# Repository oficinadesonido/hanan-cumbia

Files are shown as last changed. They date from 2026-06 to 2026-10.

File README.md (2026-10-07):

# HANAN CUMBIA · Batería electrónica (Arduino Nano)

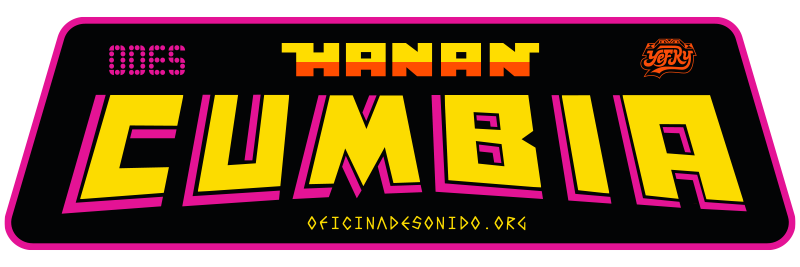
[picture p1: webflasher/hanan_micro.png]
HANAN CUMBIA


Caja de ritmos / batería electrónica tropical de **Oficina de Sonido** (desde 2020). Plataforma
**Arduino Nano (ATmega328P)** + DAC externo **MCP4901** por SPI, síntesis por wavetable.
Dos versiones de hardware con **el mismo circuito y el mismo firmware**:

| Versión | PCB | Qué es |
|---|---|---|
| **Clásica** | `hardware/hananClasicaPcb/` | 77×92 mm, 8 pulsadores en placa, jack DC 9 V, va en caja. |
| **Mini** | `hardware/hananMiniPcb/` | 150×75 mm (= panel), calado para 4 botones arcade, se alimenta por USB. Para talleres. |

El rediseño 2026 en ESP32 es otro producto: `../hanan-mk2/`.

## 🔥 Web Flasher / Hanan Estudio

👉 **https://oficinadesonido.github.io/hanan-cumbia/webflasher/** (GitHub Pages desde `main`;
todo push a `main` queda publicado al toque). Chrome/Edge/Opera de escritorio (Web Serial).
`hananFabrica/` es el flasher de fábrica (solo firmware). Notas de diseño en `webflasher/README.md`.

## Estructura

```
hardware/hananClasicaPcb/   PCB clásica v2.0 (KiCad 10)      ← ver su README
hardware/hananMiniPcb/      PCB Mini v2.0 (KiCad 10)
firmware/hanan26Taller/     Firmware actual (Taller 2026; de acá salen los builds del Estudio)
firmware/tests/             Sketches de diagnóstico (DAC, potes, pines, motor de audio)
firmware/legacy/HTRCMB_10/  Firmware original del que deriva todo (histórico)
webflasher/                 Hanan Estudio + Lab + flasher (HTML/JS, STK500v1)
hananFabrica/               Flasher de fábrica
docs/                       Revisión eléctrica, capas EasyEDA, SVG de calados del panel Mini
```

Perfil de fabricación: **tht** (JLC solo PCB, se suelda en taller). Regla: toda placa lleva en silk
`<proyecto> vX.Y AAAA-MM-DD` = nombre del zip de gerbers (title block del PCB).

## Cambios v2.0 de ambas PCB (2026-10-07)
- RC en Vref del DAC (R6 1k + C2 10 µF) y 100 nF en Vdd (C3): el ruido del USB/cargador ya no entra
  directo a la referencia del audio. Pads del LED RGB agrandados. Rótulo de versión en silk.
- Mini: los 8 pads de los cables de los botones arcade pasan a una columna de pads grandes en pares
  (blanco/rosa/amarillo/verde + GND), zona GND en toda la placa.
- Detalle y pendientes en `docs/revision-electronica-mini.md` y `hardware/hananClasicaPcb/README.md`.

## Firmware: cambios respecto al original
- **Fix de tempo (pitch ⇒ BPM):** el secuenciador se clockeaba con `micros()`, que bajo la carga de la
  ISR de audio perdía tiempo. Ahora el tempo se cuenta con un reloj estable dentro de la ISR (`audioclock`).
- **BPM por defecto = 90**; **potenciómetros invertidos** (A0/A1); **A14 neutralizado** (solo 2 potes);
  **piso de pitch en A1** para que el sample siempre suene completo.

```bash
arduino-cli compile --fqbn arduino:avr:nano firmware/hanan26Taller
arduino-cli upload  --fqbn arduino:avr:nano -p /dev/ttyUSB0 firmware/hanan26Taller
```
Requiere el core `arduino:avr` y las librerías `Bounce` y `DAC_MCP49xx`.

## Historial
El material viejo (Placa_2021, HTR_2023, hanan25, audios, códigos, backups) se movió el 2026-10-07 a
`3-archivo/hanan-cumbia-historico/` (y está en el respaldo TOSHIBA). Repo viejo `oficinadesonido/HananCumbia` (2023).

---
🤖 Mantenido con ayuda de [Claude Code](https://claude.com/claude-code) · oficinadesonido.org

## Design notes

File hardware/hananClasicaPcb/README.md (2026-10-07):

# hananClasicaPcb — Hanan Cumbia clásica, PCB principal v2.0 (2026-10-07)

Proyecto KiCad 10 armado el 2026-10-07 a partir de:
- **PCB:** `../hanan25.kicad_pcb` (77.1×92.1 mm; mismo diseño que `Hanan.kicad_pcb`/`Hanantaller.kicad_pcb`/`HTR_2023`;
  última fabricación JLC Y194, 10 u., 2025-11-14).
- **Esquemático:** copia de `hanan26/hananMiniPcb/hananMiniPcb.kicad_sch` (mismos refs y UUIDs que la PCB) +
  `J1` jack DC y `D2` diodo serie a `+9V`/VIN (net `VIN_JACK`). El `.sch` legacy `BD1.sch` queda como histórico.
  Los enlaces sch↔pcb coinciden (UUID de símbolo = path de huella), así que "Actualizar PCB desde esquemático" en el GUI
  no debería mover nada.

## Cambios v2.0 (iguales a hananMiniPcb v2.0)
- `R6` 1 kΩ + `C2` 10 µF: RC en Vref del MCP4901 (U1.6, net `VREF`); `C3` 100 nF en Vdd (U1.1). Cara B, borde izquierdo
  junto a R3 (R6 x=52.6, C2 x=51.8, C3 y=105.8). El +5C que entraba al pad 6 se cortó en (61.9,112.6) y se reruteó.
- Pads de `D1` (LED RGB) 1.25×1.8 mm (anillo 0.175 ≥ 0.13 JLC). Solo en la instancia del PCB.
- Title block (rev `v2.0`, fecha) + silk `hananClasicaPcb ${REVISION} ${ISSUE_DATE}` en F y B (y=160.6).
- DRC: 0 sin conectar, 0 errores. Warnings preexistentes: libs `OdeS`/`SWITCH`/`Arduino` no configuradas, silk al
  borde, textos XA1, vía colgada de `Net-(J2-Pad1)` en (113.3,149.7).

## Al fabricar
Fecha del title block = fecha de orden (sch y pcb) → zip `hananClasicaPcb-v2.0-<AAAA-MM-DD>.zip`.
Pendientes 🟡 (no incluidos): R serie en clock out, protección clock in, 10 nF de reconstrucción — ver
`hanan26/docs/revision-electronica-mini.md` (aplica igual a esta placa).

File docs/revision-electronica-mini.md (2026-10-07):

# Revisión electrónica — hananMiniPcb (Hanan Cumbia Mini, Nano) — 2026-10-07

Fuente: netlist exportado con `kicad-cli` de `hananMiniPcb.kicad_sch` (38 nets, 23 componentes) + `hananMiniPcb.kicad_pcb`
(estado v2.0 en preparación: columna de pads para botones arcade ya hecha). Todo hallazgo nombra refs reales.
Contexto: placa THT que se suelda en taller; firmware `hanan26Taller`; se alimenta por el USB del Nano (+5V).

## 🔴 Alta (conviene resolver antes de fabricar)

1. **Cero capacitores de desacople en toda la placa.** El único cap es C1 (10 µF, acople de audio). El DAC
   MCP4901 (U1) tiene Vdd (pin 1) y **Vref (pin 6) colgados directo del +5V del USB** sin ningún cap. Vref es
   la referencia del audio: todo el ruido del USB/cargador sale por el parlante.
   **Fix:** 100 nF entre U1.1 y U1.7 (GND) pegado al chip, y 100 nF + 10 µF en Vref (U1.6). Opcional y
   mejor: RC en Vref (100 Ω serie desde +5C + 10 µF a GND) para filtrar el riel. Mínimo: 2× 100 nF disco.
   El Nano trae sus propios caps, el DAC no.

2. **Anillo anular de D1 (LED RGB) fuera de regla:** pads 1.07×1.80 mm con broca 0.9 → anillo 0.085 mm
   (regla 0.10, JLC pide ≥0.13 para PTH). Son los 4 errores de DRC que quedan. JLC fabricó P169 igual, pero
   es la pieza más propensa a fallar en producción. **Fix:** agrandar los pads del footprint
   `OdeS:LED_RGB_CATCOM_sep` a ≥1.3×2.0 mm (pitch 2.0 lo permite) o broca 0.8.

## 🟡 Media (anda, pero no es best-practice)

3. **Clock out sin resistencia serie:** `ClckOut1.1` (tip) va directo a `XA1.D12`. Un corto en el jack o un
   cable conectado a otra salida carga el pin del ATmega sin límite. **Fix:** 1 kΩ en serie (R6) entre D12 y
   el jack.
4. **Clock in sin protección:** `Clckin1.1` (tip) va directo a `XA1.A5` (comparte net con A2 y con el switch
   TAP). Un trigger Eurorack de 10 V o un pulso negativo entra crudo al pin. **Fix:** 10 kΩ en serie + el
   pull-up interno alcanza para 5 V; con clamp (dos diodos 1N4148 a +5V/GND) aguanta modular.
5. **Audio out sin filtro de reconstrucción:** `U1.8 → R3 1k → C1 10µ → Out1`. El DAC de 8 bits sale con
   escalones; un 10 nF de R3 a GND (fc ≈ 16 kHz) limpia sin cambiar el carácter lo-fi. Opcional: es
   decisión de sonido, no de seguridad.
6. **Botones arcade con pull-up interno (~35 kΩ) y cables largos:** funciona (el firmware debouncea), pero
   con 30 cm de cable es antena. Si aparecen disparos fantasma en taller: 10 kΩ externos a +5C en D3/D4/D7/D8.
   No es necesario de entrada.

## ⚪ Baja / cosmético

7. `XA1.GND2` sin conectar (el socket tiene 2 GND, solo GND1 está en la net). El módulo los une
   internamente; conectarlo cuesta una pista y mejora el retorno. Igual con el 3V3 (no se usa, OK).
8. `A2` y `A5` del Nano están en la **misma net** (clock in / tap). Hoy ambos son entradas con pull-up en el
   firmware (16 y 19) → inofensivo. Si algún día el firmware pone 16 como salida, se cortocircuitan.
   Sugerencia: quitar A2 de la net en el sch (herencia del Hanan clásico).
9. Dos vías de `Net-(J2-Pin_4)` en (74.9, 86.9) y (74.7, 78.4) con cobre en una sola capa (colgadas, vienen
   de P169). Limpiar antes del export.
10. Serigrafía de los jacks y la ref de XA1 recortadas por el borde superior (15 warnings): cosmético, el
    Nano y los jacks asoman por el borde a propósito.
11. `+9V` solo llega a `XA1.VIN`: no hay jack DC en la placa (se alimenta por USB). Dejarlo como está o
    quitar el símbolo para que no confunda.

## ✅ Revisado y OK

- SPI al DAC: `~CS` D10, SCK D13, SDI D11, `~LDAC` a GND (actualización inmediata). Correcto.
- Acople de salida: C1 polarizado con el + del lado del DAC (Vout ≈ 2.5 V DC). Polaridad bien. R2 1k a GND
  como carga del DAC, HPF con carga de 10 k ≈ 1.4 Hz.
- LED RGB cátodo común: R1/R4/R5 = 220 Ω por color en D6/D5/D9 (PWM). OK.
- Potes RV1/RV2 10 k lineales, wiper a A0/A1, extremos a +5C/GND. 10 k es lo que recomienda el AVR para el
  ADC; sin cap de filtro está bien (opcional 10 nF).
- Switches de 12 mm (shift D2, play A3, rec A4, tap A5) a GND con pull-up interno: OK, estándar.
- Jacks: ring (pin 2) sin net en los tres: correcto para mono con jack TRS. Sleeve a GND.
- Botones arcade: J2 pines 1/4/5/8 → D3/D8/D4/D7 con GND alternado; coincide con el firmware
  (bouncer1=3 cencerro, bouncer4=4 kick, bouncer2=8 conga, bouncer3=7 güiro) y con los colores del panel.
- Mecánica: 4× M3 a 4.6 mm de las esquinas, calado octogonal para los 4 arcade de 24 mm, Nano y jacks al
  borde superior.

## Falsos positivos descartados

- "Dead net" en `Net-(XA1-A5_SCL)` con el switch TAP y el jack: sí la lee el MCU (A5). No es control muerto.
- `unconnected-(XA1-RESET-*)`, `AREF`, `A6/A7`, `D0/D1`: intencionales (sin botón de reset, UART libre para
  flashear).

## Hecho en v2.0 (2026-10-07, decisión de Daniel: "las altas, versión simple con una R y 2 caps")

- **Item 1** → `R6` 1 kΩ en serie +5C→Vref (U1.6, net nueva `VREF`), `C2` 10 µF electrolítico Vref→GND
  (misma huella que C1, `CP_Radial_D4.0mm_P2.00mm`), `C3` 100 nF disco (`C_Disc_D5.0mm_W2.5mm_P5.00mm`)
  Vdd→GND. fc del RC ≈ 16 Hz. En el PCB van en cara B debajo de U1 (R6 en y 141.6, C2/C3 en y 144.6–146.6).
  El +5C que seguía hacia RV1 a través del pad 6 se reruteó (2 vías); CS del DAC quedó donde estaba.
- **Item 2** → pads de D1 ahora 1.25×1.8 mm (broca 0.9 → anillo 0.175 mm ≥ 0.13 JLC). Se movió la pista
  BA de D1 que pasaba a 0.14 mm del pad 2 (ahora corre en y 90.6). Cambio solo en la instancia del PCB,
  la huella `OdeS:LED_RGB_CATCOM_sep` de la lib sigue igual.
- **Item 9** → borradas las 2 vías colgadas de `Net-(J2-Pin_4)` y sus stubs.
- Rótulo de versión: title block del PCB y del sch (`hananMiniPcb` · rev `v2.0` · fecha 2026-10-07) y texto
  `hananMiniPcb ${REVISION} ${ISSUE_DATE}` en F.SilkS y B.SilkS (espejado) en (78, 149.9), 1.2 mm.
  🔴 Al exportar: si la fecha de orden no es 2026-10-07, cambiar la fecha del title block (sch + pcb) y
  nombrar el zip `hananMiniPcb-v2.0-<fecha>.zip`.
- DRC final: 0 sin conectar, 0 errores. Warnings restantes preexistentes (lib_footprint ×18, silk_edge ×15,
  silk_overlap ×7, texto XA1 ×4, vía colgada de R5 en (75.76,135.14)).
- Netlist ↔ PCB cruzado: coincide en todos los pads con número (PLAY1/REC1/SHIFT1/TAP1 existen solo en
  el sch, sin huella, como venía).

## Pendiente / no incluido (Daniel decide en otra rev)

- 🟡 items 3–6 (R serie clock out, protección clock in, filtro 10 nF, pull-ups externos).
- ⚪ 7 (XA1.GND2), 8 (A2+A5 misma net), 10 (silk recortada), 11 (+9V/VIN sin jack).
- Vía colgada de `Net-(R5-Pad1)` en (75.76,135.14): preexistente, sin efecto.

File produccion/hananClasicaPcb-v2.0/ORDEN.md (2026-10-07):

# hananClasicaPcb v2.0 — orden JLCPCB

- **Archivo subido:** `hananClasicaPcb-v2.0-2026-10-07.zip` (gerbers + Excellon, generados con kicad-cli 10.0.1 desde
  `hardware/hananClasicaPcb/hananClasicaPcb.kicad_pcb`, DRC 0 errores, 2026-10-07).
- **Cantidad pedida:** 5
- **Placa:** 2 capas, 77.1 × 92.1 mm, 1.6 mm, placa pelada (THT, sin ensamble). Color/acabado: el habitual de ODS.
- **J2:** header 1x08 reemplazado por `ODS:Hanan_PadsArcade_1x08_Pares_Compacto` (columna de 8 pads ø3.5 en x=120.7, y 102–146, grupos de pares espejados: 102/107, 114/119 | 129/134, 141/146). Gerber regenerado el mismo día; el ítem Y668 del carrito se reemplaza.
- **Rótulo en silk:** `hananClasicaPcb v2.0 2026-10-07` (F y B).
- **Orden JLC:** cotización/ítem **Y670-2447297A** (reemplaza a Y668 y Y669, gerbers previos sin la columna / sin espejar; subido al carrito 2026-10-07, 5 u. × 2 capas verde 1.6 HASL = USD 4.00 oferta). Fecha de pago / invoice: _(completar al pagar)_
- **Recibida / probada:** _(completar; luego registrar en `0-libs/ods-fab-data/placas_verificadas.csv`)_

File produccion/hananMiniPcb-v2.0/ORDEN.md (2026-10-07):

# hananMiniPcb v2.0 — orden JLCPCB

- **Archivo subido:** `hananMiniPcb-v2.0-2026-10-07.zip` (gerbers + Excellon, generados con kicad-cli 10.0.1 desde
  `hardware/hananMiniPcb/hananMiniPcb.kicad_pcb`, DRC 0 errores, 2026-10-07).
- **Cantidad pedida:** 20
- **Placa:** 2 capas, 150 × 75 mm, 1.6 mm, placa pelada (THT, sin ensamble). Color/acabado: el habitual de ODS.
- **Rótulo en silk:** `hananMiniPcb v2.0 2026-10-07` (F y B).
- **Orden JLC:** cotización/ítem **Y667-2447297A** (subido al carrito 2026-10-07, 20 u. × 2 capas verde 1.6 HASL = USD 25.70 merchandise). Fecha de pago / invoice: _(completar al pagar)_
- **Recibida / probada:** _(completar; luego registrar en `0-libs/ods-fab-data/placas_verificadas.csv`)_

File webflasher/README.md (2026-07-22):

# HANAN CUMBIA · Web Flasher (Studio) — notas para editar el diseño

Web en vivo: **https://oficinadesonido.github.io/hanan-cumbia/webflasher/**
Publica GitHub Pages directo desde la rama `main` → **todo push a `main` queda en producción al toque**.
Para experimentar tranquilo: trabajar en una rama y pedir merge.

## Dónde vive el diseño gráfico

| Archivo | Qué es |
|---|---|
| `index.html` | **Hanan Estudio** (página principal): secuencias + firmware, **sin** la sección de subir samples (en revisión). |
| `lab.html` | **Hanan Lab**: la app completa, igual al Estudio **más** la pestaña Samples. Mismo `studio.js` (detecta la página por `window.HANAN_LAB` y por presencia de elementos). Comparten proyecto vía localStorage. |
| CSS común | **Todo el CSS está inline en el `<style>` del `<head>` de cada página** (index y lab son casi idénticos: si se toca la estética, actualizar ambos). Paleta en `:root`: `--pink #ff1f8e`, `--yellow #ffd400`, `--orange #ff6a00`, fondo `--bg #0a0a0a`, y los colores de los botones de la máquina `--rojo #ff1f8e`, `--blanco #eaeaea`, `--verde #3ddc84`, `--amarillo #ffd400`. Ahí están tabs, tarjeta, grilla, botones. |
| `studio.js` | Lógica de UI + flasheo. Genera la grilla de secuencias dinámicamente; cada pista lleva el color de su botón físico (definido en la tabla `CH`: rojo=Conga, blanco=Campana, verde=Huiro, amarillo=Bombo). Los selectores de banco/preset siguen el mismo orden físico (tabla `SELBTNS`; el índice de firmware es rojo=2, blanco=0, verde=3, amarillo=1). Sin glows ni degradados: colores planos. |
| `hanan_micro.png` | Logo del header. |
| `../hananFabrica/index.html` | Segundo flasher autónomo (solo firmware de fábrica), con su propio CSS inline. Si se cambia la estética, actualizar también acá para que queden parejos. |

## Reglas de oro

1. **Cache-busting:** los scripts se cargan como `studio.js?v=N` y `firmware_studio.js?v=N` al final de `index.html` **y** `lab.html`. Si tocás `studio.js`, **subí el número `?v=`** en las cuatro etiquetas (dos por página) para que los navegadores no sirvan la versión vieja.
2. **No tocar:** `sampler.html`, `seq.html`, `studio.html` son solo redirects a `index.html`.
3. **No editar a mano:** `firmware_studio.js`, `firmware.js`, `firmware_bank.js`, `firmware_presets.js`, `firmware.hex` — se generan del build del firmware (`build/`, `build_bank/`).
4. **Legacy:** `app.js`, `sampler.js`, `seq.js` son restos de versiones anteriores del flasher; el Studio actual usa solo `studio.js` + `firmware_studio.js`.
5. La página necesita **Chrome/Edge/Opera de escritorio** (Web Serial) para flashear; el diseño se puede previsualizar en cualquier navegador abriendo `index.html` local con doble clic.

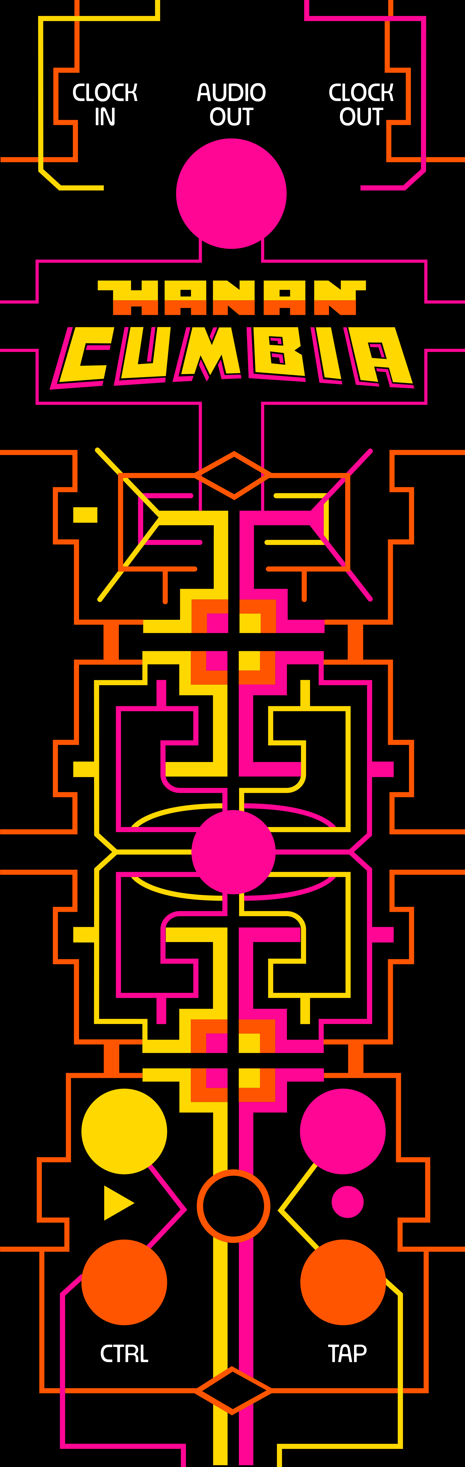
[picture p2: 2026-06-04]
docs/Hanan-capas-HIRES-EASYEDA.png

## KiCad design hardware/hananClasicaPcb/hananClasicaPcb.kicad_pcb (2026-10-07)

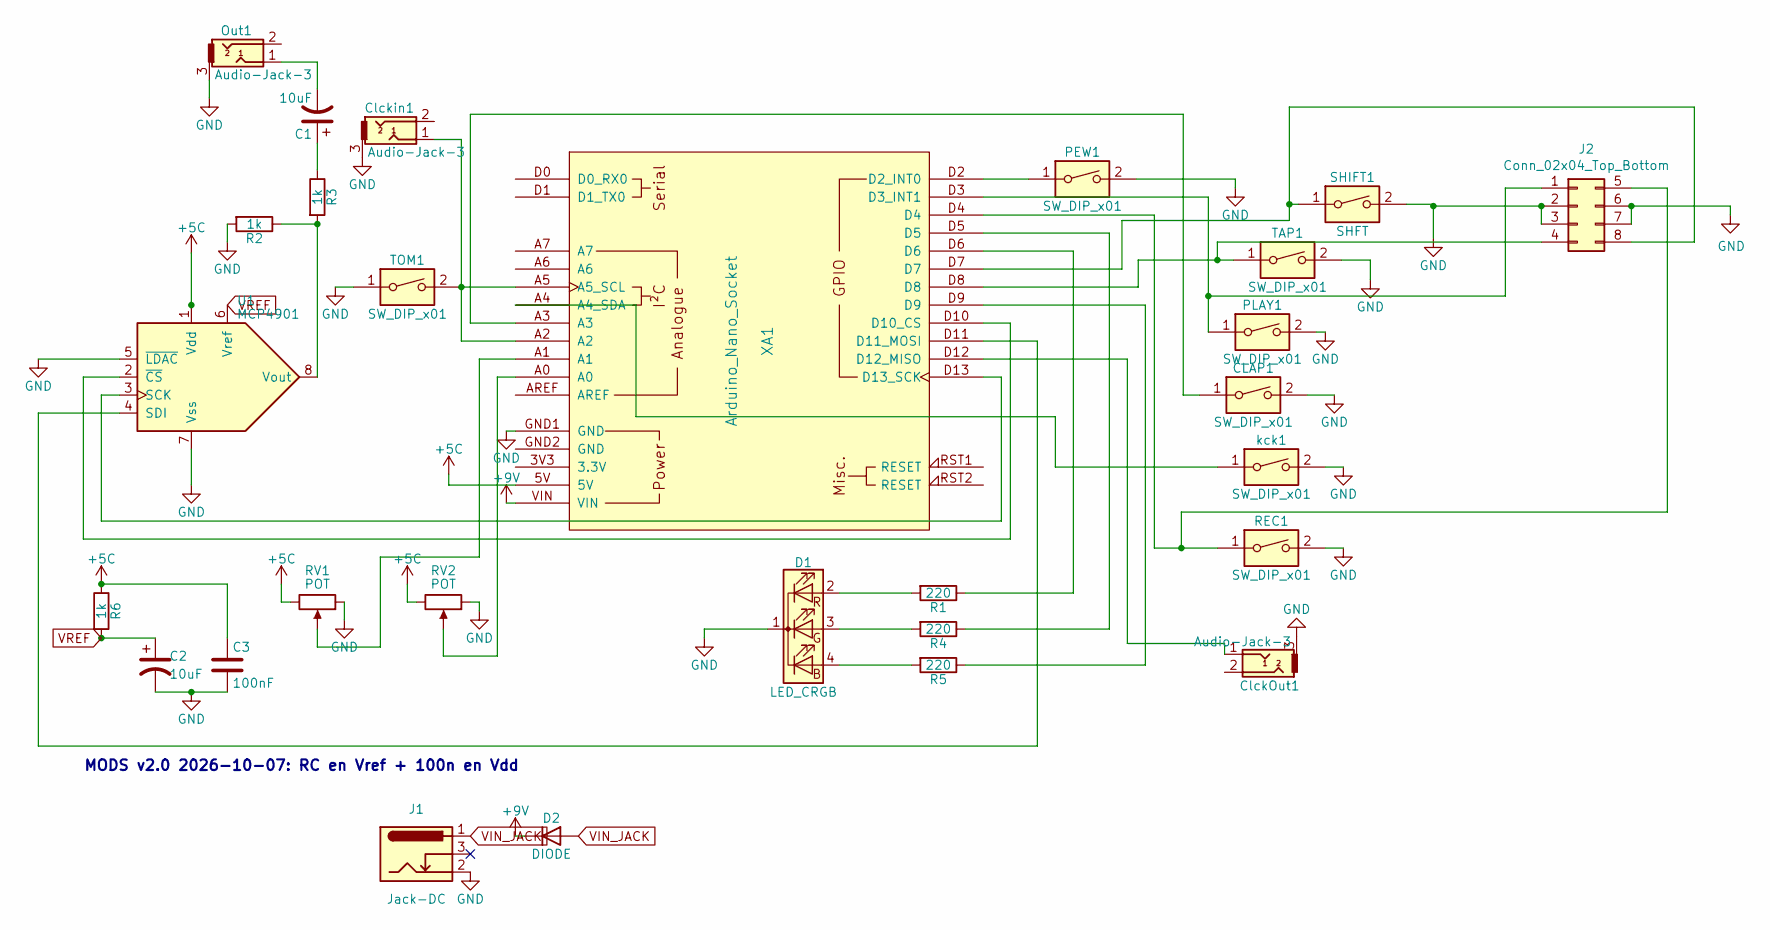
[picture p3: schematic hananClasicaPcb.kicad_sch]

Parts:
C1, C2: 10uF; CP_Radial_D4.0mm_P2.00mm
C3: 100nF; C_Disc_D5.0mm_W2.5mm_P5.00mm
CLAP1: SW_DIP_x01; SW_PUSH-12mm
ClckOut1: Audio-Jack-3; CONN_Jack_Female_3.5mm_THD
Clckin1: Audio-Jack-3; CONN_Jack_Female_3.5mm_THD
D1: LED_CRGB; LED_RGB_CATCOM_sep
D2: DIODE; D_A-405_P7.62mm_Horizontal
J1: Jack-DC; jack_dc_solder
J2: Conn_02x04_Top_Bottom; Hanan_PadsArcade_1x08_Pares_Compacto
Out1: Audio-Jack-3; CONN_Jack_Female_3.5mm_THD
PEW1: SW_DIP_x01; SW_PUSH-12mm
PLAY1: SW_DIP_x01; SW_PUSH_6mm
R1, R4, R5: 220; R_Axial_DIN0207_L6.3mm_D2.5mm_P7.62mm_Horizontal
R2, R3, R6: 1k; R_Axial_DIN0207_L6.3mm_D2.5mm_P7.62mm_Horizontal
REC1: SW_DIP_x01; SW_PUSH_6mm
RV1, RV2: POT; Potentiometer_Alps_RK09K_Single_Vertical
SHIFT1: SHFT; SW_PUSH_6mm
TAP1: SW_DIP_x01; SW_PUSH_6mm
TOM1: SW_DIP_x01; SW_PUSH-12mm
U1: MCP4901; DIP-8_W7.62mm_Socket_LongPads
XA1: Arduino_Nano_Socket
kck1: SW_DIP_x01; SW_PUSH-12mm

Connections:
+5C: C3.1, R6.1, RV1.3, RV2.3, U1.1 (Vdd), XA1.5V
+9V: D2.1 (K), XA1.VIN
GND: C2.2, C3.2, CLAP1.2, ClckOut1.3, Clckin1.3, D1.1 (K), J1.2, J2.2, J2.3, J2.6, J2.7, Out1.3, PEW1.2, PLAY1.2, R2.2, REC1.2, RV1.1, RV2.1, SHIFT1.2, TAP1.2, TOM1.1, U1.5 (~LDAC), U1.7 (Vss), XA1.GND1 (GND), kck1.2
unnamed: C1.1, R3.1
unnamed: C1.2, Out1.1
unnamed: CLAP1.1, XA1.A3
unnamed: ClckOut1.1, XA1.D12 (D12_MISO)
unnamed: D1.2 (RA), R1.2
unnamed: D1.3 (GA), R4.2
unnamed: D1.4 (BA), R5.2
unnamed: D2.2 (A), J1.1
unnamed: J2.1, PLAY1.1, XA1.D3 (D3_INT1)
unnamed: J2.4, TAP1.1, XA1.D8
unnamed: J2.5, REC1.1, XA1.D4
unnamed: J2.8, SHIFT1.1, XA1.D7
unnamed: PEW1.1, XA1.D2 (D2_INT0)
unnamed: R1.1, XA1.D6
unnamed: R2.1, R3.2, U1.8 (Vout)
unnamed: R4.1, XA1.D5
unnamed: R5.1, XA1.D9
unnamed: RV1.2, XA1.A1
unnamed: RV2.2, XA1.A0
unnamed: U1.2 (~CS), XA1.D10 (D10_CS)
unnamed: U1.3 (SCK), XA1.D13 (D13_SCK)
unnamed: U1.4 (SDI), XA1.D11 (D11_MOSI)
unnamed: XA1.A4 (A4_SDA), kck1.1
VREF: C2.1, R6.2, U1.6 (Vref)

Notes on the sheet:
MODS v2.0 2026-10-07: RC en Vref + 100n en Vdd

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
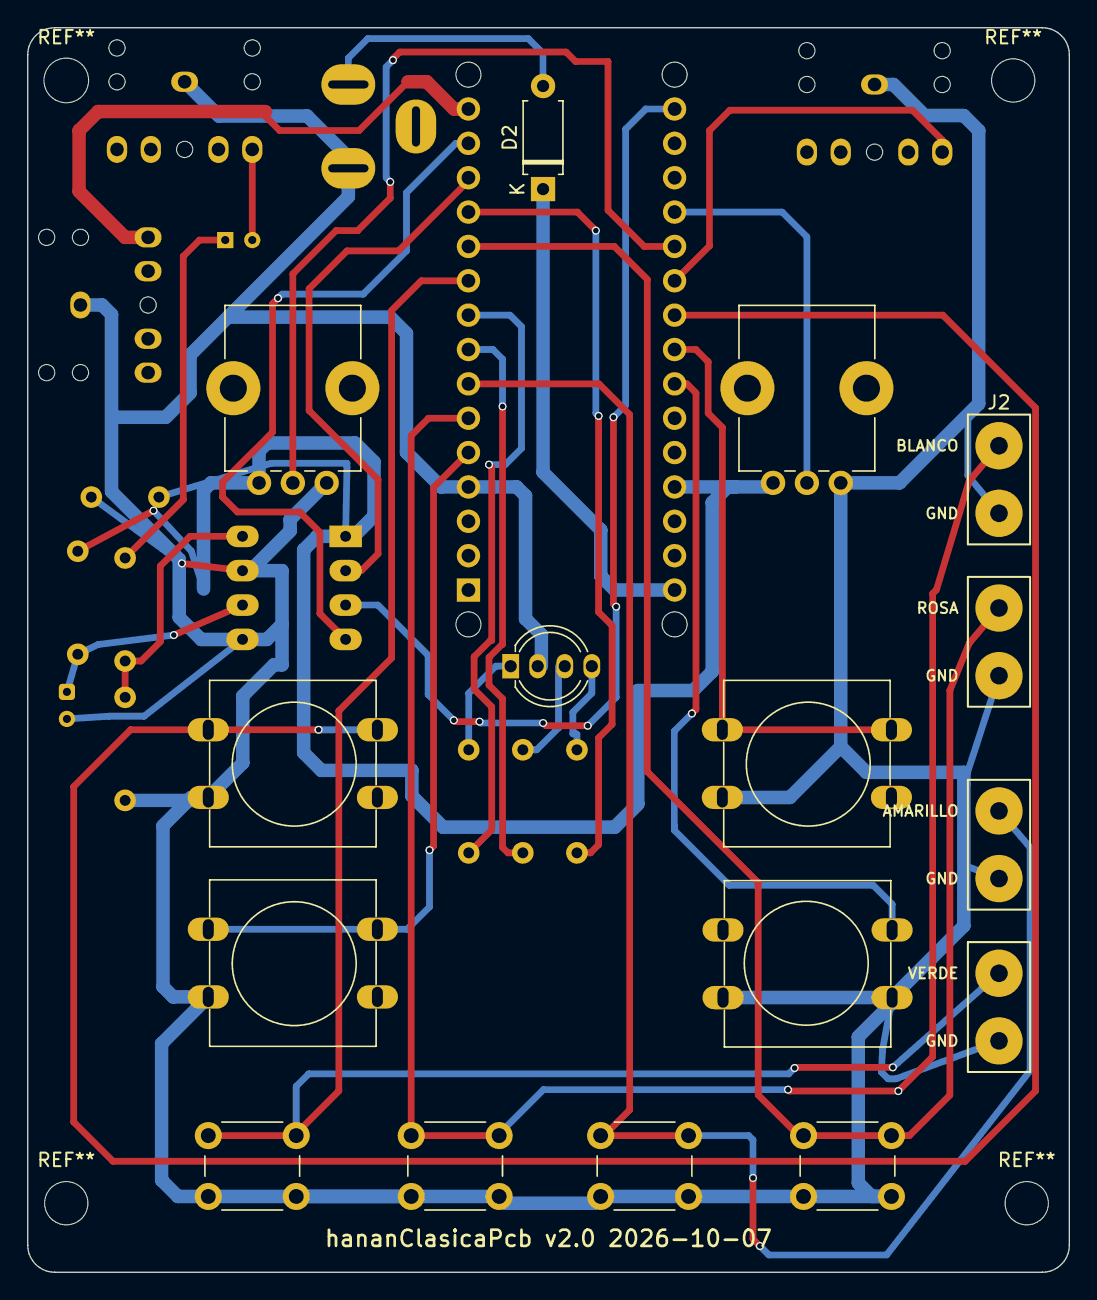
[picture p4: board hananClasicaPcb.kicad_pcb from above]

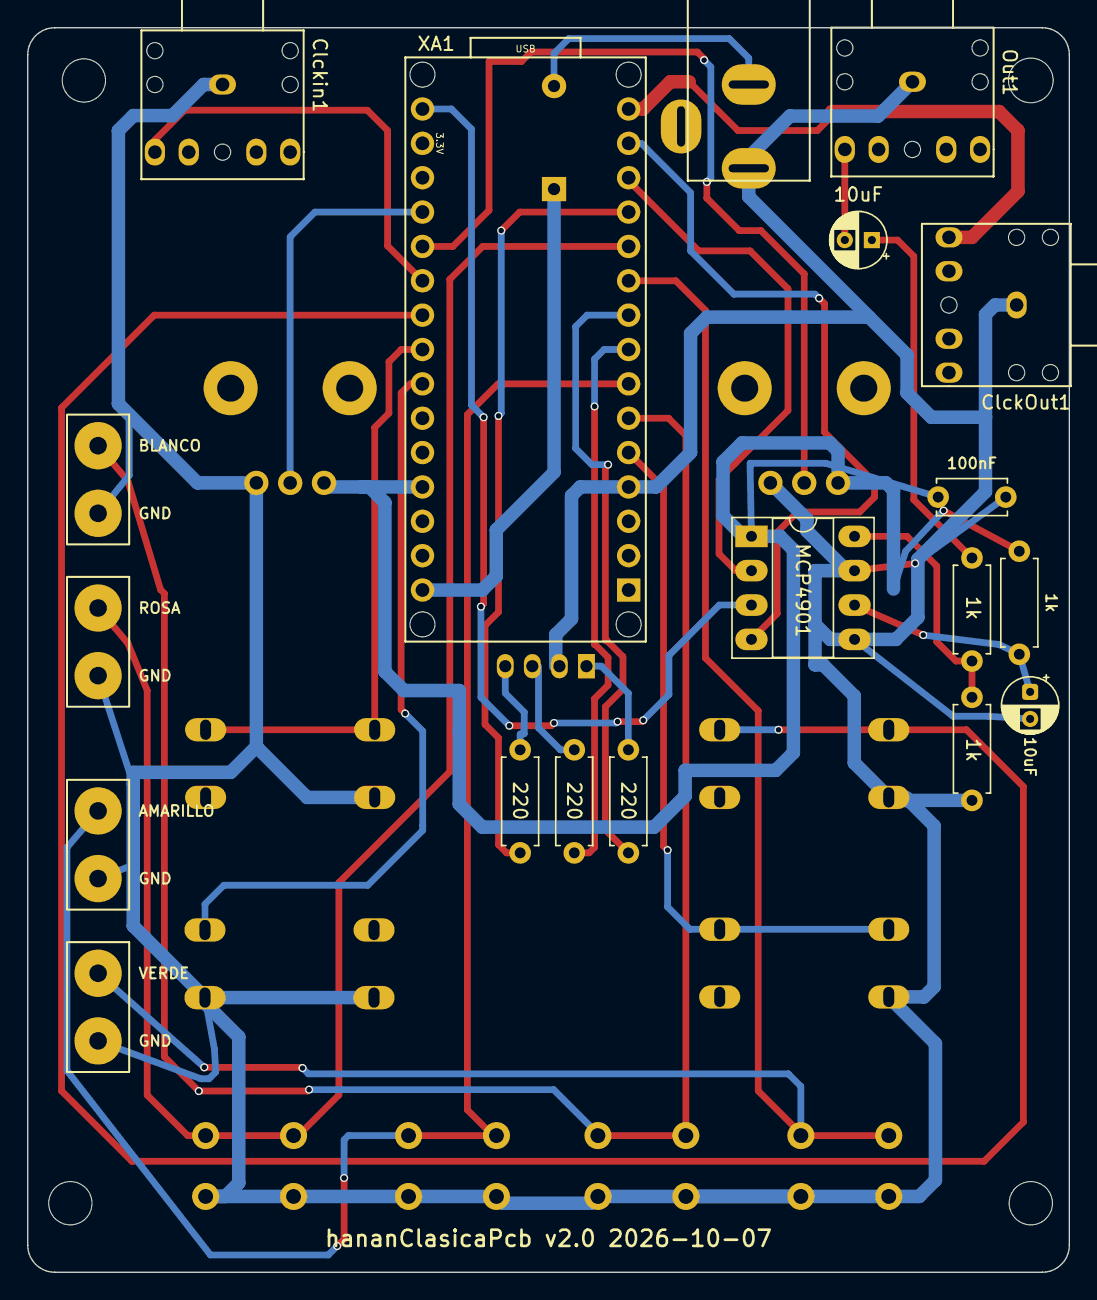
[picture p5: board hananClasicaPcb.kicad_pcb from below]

Board: 2 copper layers, 77.0 x 92.0 mm, 28 parts (15 on the bottom side), 29 nets.

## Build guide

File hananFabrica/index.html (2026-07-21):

HANAN CUMBIA

# Fábrica · grabar firmware

⚡ Conectar y grabar firmware

Bootloader: Verificar al grabar Invertir reset (DTR/RTS)

0%

Cómo usar: conectá el Arduino Nano por USB, hacé clic en Conectar y grabar y elegí el puerto (suele aparecer como CH340 o USB-Serial). No abras el Monitor Serie ni el IDE al mismo tiempo.
Si dice que el bootloader no responde, marcá Invertir reset y reintentá.
Requiere Chrome, Edge u Opera de escritorio (la Web Serial API no existe en Firefox/Safari ni móvil).

oficinadesonido.org · hanan cumbia

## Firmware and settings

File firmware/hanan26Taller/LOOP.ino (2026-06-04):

unsigned long recordoffsettimer,offsetamount,taptempof;
int potX;

void loop() {
uint32_t now = readAudioClock(); // base de tiempo estable para todo el secuenciador
bouncertap.update ( );
bouncer1.update ( );
bouncer2.update ( );
bouncer4.update ( );
bouncer3.update ( );
 LEDS();
  BUTTONS();
  RECORD();

  // --- Presets: guardar el banco activo en EEPROM al PARAR (play 1->0) ---
  if (prevPlayState == 1 && play == 0) saveBankToEE(presetbank);
  prevPlayState = play;

  // --- Cambio de banco de presets: STOP + shift + hold 2s de un color ---
  if (play == 0 && shift == 0) {
    byte hb = 255;
    if      (bouncer2.read() == 0) hb = 0;   // azul
    else if (bouncer4.read() == 0) hb = 1;   // amarillo
    else if (bouncer1.read() == 0) hb = 2;   // rojo
    else if (bouncer3.read() == 0) hb = 3;   // verde
    if (hb != 255) {
      if (hb != holdBtn) { holdBtn = hb; holdStart = now; }
      else if ((uint32_t)(now - holdStart) > 128000000UL) { switchPresetBank(hb); holdBtn = 255; }  // ~2 s
    } else holdBtn = 255;
  } else holdBtn = 255;

 // dd++;
 // if (dd==0){
//pot1=(1023-analogRead(1));
//  pot1=12;
//  pot2=256;
//pot2=((1023-analogRead(0)));

if (noise_mode==0)
{
pot1=(((1023-analogRead(1)))>>1)+2;
pot2=(((1023-analogRead(0)))>>2)+32;
}

if (noise_mode==1)
{
  if (shift_latch==0)
  {
pot1=(((1023-analogRead(1)))>>1)+1;
pot2=(((1023-analogRead(0)))>>2)+1;
  }
    if (shift_latch==1){

 pot3=((1023-analogRead(1)))<<4; ////////////////MAKE ME BETTERERER  
 pot4=(1023-analogRead(0))<<2;

}}

// Piso de pitch del pote A1 (tick/conga). Por debajo de ~21 el incremento de fase
// es tan chico que el sample no alcanza a reproducirse y queda "flotando".
// Valor medido en la placa: raw~982 -> incremento 21 (punto donde suena bien).
if (pot1 < 21) pot1 = 21;

 trigger_in_read=digitalRead(16);
 
 
  if (trigger_in_read==1 && prev_trigger_in_read==0)
  {
    trigger_input=1;
    if (ext_sync_mode == 1)
    {
      fake_taptempo = (now - fake_prevtap) >> 2;
      fake_prevtap = now;
    }
  }
  else
  {
    trigger_input=0;
  }

  prev_trigger_in_read=trigger_in_read;
  
  
  //////////////////////////////////////
  // trigger out
  
  eigth=loopstep%4;

  if(eigth==0)
  {
    digitalWrite(12, HIGH);
  }
  else
  {
    digitalWrite(12, LOW);
  }
  
  
  if (ext_sync_mode == 1)
  {
    taptempof=fake_taptempo;
    recordoffsettimer=now-fake_prev ;
    offsetamount=taptempof-(taptempof>>2 );
    if ((recordoffsettimer)>(offsetamount))
    {
      loopstepf=loopstep+1;
      loopstepf%=32;
    }
  }
  else
  {
taptempof=taptempo;
    recordoffsettimer=now-prev ;
    offsetamount=taptempof-(taptempof>>2 );
    if ((recordoffsettimer)>(offsetamount))
    {
      loopstepf=loopstep+1;
      loopstepf%=32;
    }
  }



  if (play==1)
  {
    if (onetime==1)
    {
      taptempo=5333333; // 90 BPM por defecto (taptempo = 480e6 / BPM, 8 pasos/beat)
      onetime=0;
    }
    else
    {
      prevloopstep=loopstep;
      preva=eigth;

      if (recordmode==1)
      {
        if (ext_sync_mode == 1)
        {
          if (trigger_input == 1)
          {
            fake_prev = now;
            loopstep++;
            loopstep%=32;
            fake_trig_cnt = 0;
          }
          else
          if (((now - fake_prev) > (fake_taptempo)) && (fake_trig_cnt < 3))
          {
            fake_prev = now;
            loopstep++;
            loopstep%=32;
            fake_trig_cnt ++;
          }
        }
        
        else if (now - prev > (taptempof) ) 
        {
          prev = now;    
          loopstep++;
          loopstep%=32;
        }
      }
    }


    // Cambio de preset cuantizado: entra recien al volver al downbeat (paso 0)
    // para que el patron nuevo arranque limpio y no salte a mitad de compas.
    if (loopstep==0) banko=pending_banko;

    B4_loop_trigger=B4_sequence[loopstep+banko];
    B1_loop_trigger=B1_sequence[loopstep+banko];
    B2_loop_trigger=B2_sequence[loopstep+banko];
    B3_loop_trigger=B3_sequence[loopstep+banko];
  }

  if (play==0){
    banko=pending_banko;   // en stop, el cambio de preset es inmediato
    loopstep=0;
    prev==0;
    B4_loop_trigger=0;
    B1_loop_trigger=0;
    B2_loop_trigger=0;
    B3_loop_trigger=0;

  }

  if (loopstep!=prevloopstep && B3_loop_trigger==1){

    B3_seq_trigger=1;
    //freq3=kickfreqsequence[loopstepf];
  }
  else {
    B3_seq_trigger=0;
  }

  if (loopstep!=prevloopstep && B2_loop_trigger==1){

    B2_seq_trigger=1;
    //freq3=kickfreqsequence[loopstepf];
  }
  else {
    B2_seq_trigger=0;
  }

  if (loopstep!=prevloopstep && B4_loop_trigger==1){

    B4_seq_trigger=1;
    //freq3=kickfreqsequence[loopstepf];
  }
  else {
    B4_seq_trigger=0;
  }

  if (loopstep!=prevloopstep && B1_loop_trigger==1){

    B1_seq_trigger=1;
  }
  else {
    B1_seq_trigger=0;
  }
  
  
  
    if (B3_trigger==1 || B3_seq_trigger==1){
    index3=0;
    accumulator3=0;
    B3_latch=1;
  }

  if (B4_trigger==1 || B4_seq_trigger==1){
    index4=0;
    accumulator4=0;
    B4_latch=1;
  }
  if (B1_trigger==1){
    index=0;
    accumulator=0;
    B1_latch=1;
  }

  if (B1_seq_trigger==1){
    index_freq_1=0;
    accu_freq_1=0;
    B1_seq_latch=1;
  }
  if (B2_seq_trigger==1){
    index_freq_2=0;
    accu_freq_2=0;
    B2_seq_latch=1;
  }

  if (B2_trigger==1){
    index2=0;
    accumulator2=0;
    B2_latch=1;
  }

  
  
  
  
  //////////////////////////////////////////////////////////////// T A P
 //////////////////////////////////////////////////////////////// T A P
/*
  if (shift==1)
  {
      if (bouncertap.fallingEdge())
      {
        t++;
        t%=2;
        tapbank[t]=((now)-prevtap)>>2;
        taptempo=((tapbank[0]+tapbank[1])>>1);
        prevtap=now;
      }
  }
*/

  if (bouncertap.fallingEdge())
  {
    if (shift == 1) // shift nestisknut
    {
      t++;
      t%=2;
      tapbank[t]=((now)-prevtap)>>2;
      taptempo=((tapbank[0]+tapbank[1])>>1);
      prevtap=now;
    }
    else
    {
      ext_sync_mode ++;
      ext_sync_mode %= 2;
    }
  }
  
/*  if (ext_sync_mode == 1)
  {
    taptempo = (now - prevtap) >> 2;
    prevtap = now;
  }
  */
}

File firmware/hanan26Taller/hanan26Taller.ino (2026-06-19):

#include <avr/pgmspace.h>
#include <avr/eeprom.h>
#include <SPI.h>
#include <Bounce.h>
#include <DAC_MCP49xx.h>

DAC_MCP49xx dac(DAC_MCP49xx::MCP4901, 10);

PROGMEM const char  noise_table[] = {};

// ===== Banco de samples (parcheable por el web flasher) =====
// Layout: [8 magic][4 voces x (offset u16 LE, length u16 LE)][datos...]
// Voces: 0=kick 1=snare 2=hat(tick) 3=bass.  Offsets ABSOLUTOS dentro de samplebank.
// magic = 48 4E 53 42 31 A5 5A 3C  ("HNSB1" + A5 5A 3C)
const uint8_t samplebank[20005] PROGMEM = {
72,78,83,66,49,165,90,60,24,0,112,22,136,22,77,11,213,33,169,20,126,54,167,23,127,127,127,127,127,127,127,127,127,127,127,127,127,127,127,127,
126,126,126,126,126,126,126,126,126,126,126,126,126,126,126,126,126,126,126,126,126,126,126,125,125,125,125,125,125,125,125,125,125,125,125,125,125,125,125,125,
125,125,125,125,124,124,124,124,124,124,124,124,124,124,124,124,124,124,124,124,124,124,124,123,123,123,123,123,123,123,123,123,123,123,123,123,123,123,123,123,
122,122,122,122,122,122,122,122,122,122,122,122,122,122,122,122,122,122,121,121,121,121,121,121,121,121,121,121,121,121,121,121,121,121,121,121,121,121,121,120,
120,120,120,120,120,120,120,120,120,120,120,120,120,120,120,120,120,120,120,120,120,120,120,120,120,120,120,120,120,120,120,119,120,119,119,119,119,119,119,119,
119,119,119,119,119,119,119,119,119,119,120,119,120,119,120,119,122,124,125,125,127,127,128,129,129,129,128,130,134,139,145,152,158,165,181,230,255,248,230,228,
240,240,233,228,228,228,224,220,217,216,216,212,209,204,199,194,192,190,189,186,184,182,179,174,168,160,153,147,142,136,130,123,116,110,103,97,92,87,82,79,
75,71,67,63,58,53,50,50,49,47,45,45,44,43,42,43,42,42,42,41,41,42,45,47,48,50,52,54,55,58,61,61,63,65,66,68,71,74,77,80,
85,89,93,96,99,104,108,112,117,121,125,129,132,137,143,149,155,162,166,171,176,182,186,191,194,195,196,196,197,198,200,201,201,201,201,202,202,203,203,202,
203,202,199,198,197,196,194,191,188,186,186,186,185,183,180,177,174,172,169,165,161,155,151,148,142,136,130,126,121,117,113,107,103,100,96,94,91,88,86,83,
80,79,76,74,71,68,64,62,60,57,55,56,57,55,54,54,54,53,53,52,51,50,50,52,53,54,55,56,55,55,56,59,60,60,61,62,63,63,64,65,
66,66,68,71,72,73,74,76,79,81,82,84,89,92,96,98,101,104,107,111,114,118,120,123,127,130,132,135,137,139,141,144,147,150,154,158,162,165,168,171,
175,178,182,186,188,191,193,196,199,201,204,206,207,208,209,210,210,210,209,209,209,210,211,210,210,211,211,211,211,212,213,213,213,212,210,208,205,204,203,201,
200,199,198,196,194,192,191,190,188,187,185,185,183,181,179,177,174,172,169,166,162,159,156,153,149,146,143,140,136,133,130,127,124,121,118,116,113,110,108,105,
103,100,98,95,93,91,88,86,84,82,80,78,76,75,73,71,70,68,67,65,64,63,62,61,60,59,58,57,57,56,55,55,55,54,54,54,54,54,54,54,
55,55,55,56,56,57,57,58,58,59,59,60,60,61,62,62,63,64,64,65,66,66,67,68,68,69,70,71,71,72,73,74,75,76,77,79,80,81,83,84,
86,87,89,90,92,94,96,97,99,101,103,105,107,109,111,113,115,117,119,121,123,125,127,129,131,133,135,137,139,141,143,145,147,149,151,153,155,158,160,162,
164,166,168,170,172,174,176,179,180,182,184,186,188,190,191,193,194,196,197,198,200,201,202,203,204,204,205,206,206,207,207,208,208,208,209,209,209,209,209,209,
209,209,208,208,208,208,207,207,206,206,205,205,204,204,203,202,202,201,200,199,199,198,197,196,195,194,193,192,191,190,189,188,187,185,184,183,182,181,179,178,
177,175,174,172,171,169,168,166,164,163,161,159,157,156,154,152,150,148,145,143,141,139,137,135,132,130,128,126,124,122,119,117,115,113,111,109,107,105,103,102,
100,98,96,95,93,92,90,89,87,86,84,83,81,80,79,78,76,75,74,73,71,70,69,68,67,66,65,64,63,62,61,60,59,58,57,57,56,55,55,54,
54,53,53,53,52,52,52,52,52,52,52,52,52,52,52,52,53,53,53,53,54,54,54,54,55,55,55,56,56,57,57,57,58,58,59,59,60,60,61,61,
62,62,63,63,64,65,65,66,66,67,68,69,69,70,71,71,72,73,74,74,75,76,77,77,78,79,80,81,81,82,83,84,85,86,86,87,88,89,90,91,
92,93,94,95,96,98,99,100,101,102,104,105,106,108,109,110,112,113,115,116,117,119,120,122,123,125,126,128,129,131,132,134,135,136,138,139,141,142,144,145,
146,148,149,150,152,153,155,156,157,158,160,161,162,164,165,166,168,169,170,172,173,174,176,177,178,180,181,182,183,185,186,187,188,190,191,192,193,194,195,196,
197,198,199,200,201,202,202,203,204,204,205,205,206,206,206,206,207,207,207,207,207,207,207,207,207,207,207,206,206,206,206,206,205,205,205,205,204,204,204,204,
203,203,203,202,202,202,201,201,200,200,200,199,198,198,197,197,196,195,195,194,193,192,192,191,190,189,188,187,187,186,185,184,183,182,181,180,179,178,177,176,
175,175,174,173,172,171,170,169,168,167,166,165,164,163,162,161,160,158,157,156,155,153,152,151,149,148,146,145,143,142,140,139,137,135,134,132,131,129,127,126,
124,123,121,119,118,116,115,113,112,110,109,108,106,105,104,102,101,100,98,97,96,95,94,93,91,90,89,88,87,86,85,84,83,82,81,80,79,78,77,76,
75,75,74,73,72,71,70,70,69,68,68,67,66,66,65,64,64,63,62,62,61,61,60,60,59,59,59,58,58,57,57,57,57,56,56,56,56,56,56,56,
56,56,56,56,56,56,56,56,56,57,57,57,57,58,58,58,59,59,59,60,60,60,61,61,61,62,62,62,63,63,63,64,64,64,65,65,65,66,66,67,
67,67,68,68,69,69,70,70,71,71,72,73,73,74,74,75,75,76,77,77,78,79,79,80,80,81,82,82,83,84,84,85,85,86,87,87,88,88,89,90,
90,91,92,92,93,94,95,95,96,97,98,98,99,100,101,102,103,104,105,106,107,108,109,110,111,112,113,114,115,116,117,118,119,121,122,123,124,125,126,127,
129,130,131,132,133,134,135,136,137,139,140,141,142,143,144,145,146,147,148,149,151,152,153,154,155,156,157,158,159,160,161,162,163,164,165,166,167,168,169,170,
171,172,173,174,175,176,177,178,179,180,181,182,183,184,185,186,187,187,188,189,190,191,192,192,193,194,195,195,196,197,197,198,198,199,199,200,200,201,201,201,
201,202,202,202,202,202,202,202,202,202,202,202,201,201,201,201,201,200,200,200,200,199,199,199,198,198,198,197,197,197,196,196,196,195,195,195,194,194,194,193,
193,192,192,191,191,191,190,190,189,188,188,187,187,186,185,185,184,183,183,182,181,180,180,179,178,177,176,176,175,174,173,172,171,171,170,169,168,167,167,166,
165,164,163,163,162,161,160,159,158,158,157,156,155,154,153,152,151,150,149,148,147,146,145,144,143,142,141,139,138,137,136,134,133,132,131,129,128,127,125,124,
123,121,120,119,118,116,115,114,112,111,110,109,108,107,105,104,103,102,101,100,99,98,97,96,95,94,93,92,91,90,89,89,88,87,86,85,85,84,83,82,
82,81,80,80,79,78,78,77,76,76,75,75,74,74,73,73,72,72,71,71,70,70,70,69,69,68,68,68,67,67,67,66,66,66,66,65,65,65,65,65,
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
};
int kick_length, tick_length, snare_length, bass_length;   // se llenan en setup() desde los descriptores
uint16_t kick_off, snare_off, hat_off, bass_off;


byte ext_sync_mode = 0;
byte fake_trigger = 0;
byte fake_trig_cnt = 0;

unsigned long fake_taptempo = 0;
unsigned long fake_prevtap = 0;
long fake_prev = 0;
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

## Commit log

2026-06-02 HANAN CUMBIA: firmware taller 2026 + web flasher
    - Fix tempo (reloj estable desde la ISR de audio), BPM por defecto 90
    - Potes invertidos, A14 neutralizado, piso de pitch en A1
    - Web flasher (Web Serial + STK500v1) con firmware embebido
    [DDS.ino, LOOP.ino, buttons.ino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]
2026-06-03 webflasher: soporte old bootloader (57600) con fallback de baud
    - Prueba 115200 y 57600 automaticamente (selector Auto/Nuevo/Viejo)
    - Reset replica la secuencia exacta de avrdude (descarga del cap 250ms)
2026-06-03 sampler (beta): cargar samples propios via parcheo del banco en el navegador
    - Firmware refactorizado a banco de samples unico con cabecera magica + descriptores
    - sampler.html/js: WAV -> resample 9804Hz/8-bit -> patch del banco -> flash
    - Presupuesto ~2s repartido entre kick/snare/hat/bass; voces vacias quedan de fabrica
    - Flasher principal sigue con firmware probado; sampler usa el firmware del banco (beta)
2026-06-04 firmware: 4 bancos de presets con persistencia EEPROM + mejoras
    - 4 bancos de presets (shift+hold 2s, blink 3x), persistencia al parar
    - Pitch 32 niveles + grids, empaquetado en flash/EEPROM (magic HPRSB1)
    - Fix off-by-one en presets (banko 0/32/64/96, antes 0/31/63/95)
    - Cambio de preset cuantizado al downbeat (sin salto a mitad de compas)
    - LED: stop=color del banco, play=color del preset
    - Bass de fabrica recortado 0.09s para hacer lugar en flash
    - Web flasher y sampler resincronizados con este firmware (bank_total=20705)
    [LOOP.ino, buttons.ino, hanan26Taller.ino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]
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2026-06-04 editor de secuencias (web) + firmware 4 bancos en flash
    - Firmware: bloque de presets ahora con 4 bancos en flash (parcheable), reinit EEPROM por banco
    - Bass de fabrica recortado un poco mas (~0.62s) para hacer lugar
    - seq.html/seq.js: editor TR-808 (paleta HANAN), 32 pasos x 4 canales + lane de pitch para conga/campana
    - Selector de banco (1-4) y preset (1-4); decode/encode bit-exacto del bloque de presets
    - Al grabar reescribe los 4 bancos y bumpea version para que la placa recargue
    - Embeds y links cruzados (flasher/sampler/editor) actualizados
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2026-06-04 editor: colores planos por grupo estilo TR-808 (magenta/naranja/amarillo/blanco) + cuadrito con valor de pitch al arrastrar
2026-06-04 HANAN CUMBIA Studio: app unificada (link unico) samples+secuencias+preview
    - studio.html/js + firmware_studio.js: una sola app, una imagen, un flasheo (samples y presets conviven)
    - Preview fiel en el navegador (emula 9.8kHz zero-order-hold + 8-bit + pitch por acumulador)
    - Guardado de proyecto (localStorage + exportar/importar .json)
    - index.html ahora ES el Studio; sampler/seq/studio.html redirigen al index
2026-06-04 texto a español neutro (sin voseo) en el Studio y el README
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2026-06-05 webflasher: bump cache version a v=3 para que cargue el studio.js con el boton de fabrica
2026-06-10 diagnostico hw audio + fuentes PCB hanan mini
    - sketches de test aislados para depurar el camino de audio:
    dac_test, dac_static_test, pin_wiggle_test, d13_high_test,
    audio_engine_test. Sirvieron para hallar un Nano con el pin
    D13 (SCK) muerto: sin clock SPI, el DAC nunca sonaba.
    - fuentes KiCad de la placa hanan mini (esquematico + PCB).
    - gitignore: backups de KiCad, .history del editor y locks.
    [BD1.kicad_sch, BD1.sch, Hanan.kicad_pcb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]
2026-06-19 hananFabrica: firmware de fabrica SIN persistencia (siempre 4 ritmos de fabrica al reiniciar)
    Guarda -DFABRICA en setup(): restaura los 4 bancos de fabrica en EEPROM en
    cada arranque, asi al reiniciar siempre suenan los ritmos originales. La
    version taller (editable) conserva su persistencia. firmware.js regenerado
    (30188 bytes) y bump cache a v=2.
2026-07-16 webflasher: README con notas de diseño para JKO (CSS inline, cache ?v=, archivos generados)
2026-07-21 Fix clic al final de la clave/campana: lectura fuera del samplebank
    El motor DDS reproducia el indice == length (guardas con > en vez de >=),
    un byte DESPUES del final del sample. En HTRCMB_10 era inofensivo de
    casualidad (caia en el primer byte ~127 de la tabla vecina), pero con el
    samplebank unico el bass quedo ultimo y su byte one-past cae fuera del
    array: en flash habia un 0 -> pico de -127 = clic al final de cada golpe
    de bass/campana.
    - DDS.ino: guardas de fin de sample a >= (las 6 voces).
    - DDS.ino: indices reverse a (idx-(length-1))*-1; antes en idle leian
    [length] permanentemente (DC de -127 en reverse con el banco nuevo).
    - Regenerados firmware_studio/bank/presets/firmware.js, f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
    [DDS.ino]
2026-07-22 Studio: feedback de diseño JKO — sin glows, colores por botón físico, textos
    - Sin box-shadow en botones de banco/preset y pasos (stroke/fill solamente)
    - Selectores banco/preset en orden físico rojo/blanco/verde/amarillo (blanco
    reemplaza azul en la web); mapean al índice real del firmware (2/0/3/1)
    - Pistas del secuenciador con el color de su instrumento (se va el g0-g3 808)
    - Samples con nombres del aparato + punto de color, en orden de botones
    (verde=Huiro, amarillo=Bombo: verificado contra DDS.ino y samples del hex;
    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
2026-07-22 Studio: pasos del secuenciador con stroke a color pleno del instrumento
    Inactivo = borde del color del canal (todos los pasos de Huiro verdes, etc.),
    activo = fill; mismo lenguaje stroke/fill de los selectores de banco/preset.
    Celdas de pitch con borde al 45% para mantener jerarquía.
2026-07-22 Studio fix: --pc local en .pad/.pcell pisaba el color heredado de la fila
    Todos los pasos quedaban rosados (el default). El fallback vive ahora en
    #grid y cada fila hereda su color de instrumento.
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2026-10-07 hananMiniPcb v2.0: pads arcade en columna, RC en Vref + 100n en Vdd, pads D1, rótulo de versión
    - J2 header 1x08 -> huella ODS:Hanan_PadsArcade_1x08_Pares (8 pads 3.5 mm en columna,
    pares señal/GND, orden blanco/rosa/amarillo/verde), zona GND a toda la placa, M3 como huellas.
    - Contorno 150x75 reconstruido del gerber JLC P169.
    - R6 1k + C2 10u en Vref (net VREF), C3 100n en Vdd del MCP4901; +5C reruteado.
    - Pads de D1 1.25x1.8 (anillo 0.175); stubs/vías colgadas de Pin_4 borrados.
    - Title block + silk 'hananMiniPcb ${REVISION} ${ISSUE_DATE}' en F y B.
    - docs/revision-electronica-mini.md: revisión eléctrica y alcance de la rev.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
    [hananMiniPcb.kicad_pcb, hananMiniPcb.kicad_sch]
2026-10-07 hananMiniPcb: silk muestra valor (1k/10uF/100nF) en R6/C2/C3 en vez de la ref, como el resto
    Claude-Session: https://claude.ai/code/session_018KSRbDX7mTqiibDixEKAXu
    [hananMiniPcb.kicad_pcb]
2026-10-07 Reorganización: repo en la raíz de hanan-cumbia, hardware/ firmware/ docs/, PCB clásica v2.0
    - Raíz del repo = hanan-cumbia/ (antes hanan26/); webflasher/ y hananFabrica/ siguen en la raíz
    (GitHub Pages no cambia).
    - hardware/hananMiniPcb (limpio: solo pro/sch/pcb/bom) y hardware/hananClasicaPcb (nuevo, v2.0 con
    RC en Vref, 100n en Vdd, pads D1, rótulo de versión; sch = el del Mini + J1/D2).
    - firmware/hanan26Taller, firmware/tests/*, firmware/legacy/HTRCMB_10.
    - docs/: revisión eléctrica, capas EasyEDA, SVG de calados del panel Mini.
    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
    [BD1.sch, Hanan.kicad_pcb, Hanantaller.kicad_pcb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]
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2026-10-07 hananClasicaPcb v2.0: J2 header -> columna de pads arcade compacta (ODS), gerber regenerado
    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
    [hananClasicaPcb.kicad_pcb, hananClasicaPcb.kicad_sch, hananMiniPcb.kicad_sch]
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2026-10-07 hananClasicaPcb v2.0: columna de pads arcade con grupos espejados; gerber regenerado
    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
    [hananClasicaPcb.kicad_pcb]
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2026-10-19 Revert "Lab: samples a la velocidad real de cada voz y sin pisar el programa"
    This reverts commit cb4d97f.
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2026-10-22 revertir Fábrica y Lab a su estado original: los cambios de diseño son solo del Estudio
    Deshace fondo gris, cabecera nueva, brillo, #dbdbdb y quita-Rayo en hananFabrica y lab.html.
    Esos dos no se están trabajando; el rediseño aplica solo a webflasher/index.html (Estudio).
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
